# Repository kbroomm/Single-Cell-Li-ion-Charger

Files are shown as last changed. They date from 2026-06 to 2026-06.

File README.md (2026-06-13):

# Li Charger

KiCad PCB design for a single-cell lithium-ion battery charger, with a 5V USB-C input and 10-LED charge level indicator.

## Features

- **BQ24092** linear charger IC (Texas Instruments)
- **LM3914** dot/bar display driver for charge indication
- USB-C power input
- JST battery connector

## Project structure

```
├── hardware/              KiCad schematic, PCB, and custom libraries
│   ├── Li Charger.kicad_pro
│   ├── Li Charger.kicad_sch
│   ├── Li Charger.kicad_pcb
│   └── libs/              Custom symbol and footprint imports
├── manufacturing/
│   └── gerbers/           Fabrication outputs (Gerber + drill files)
├── datasheets/        	   Component reference PDFs
├── 3D models/             Component models not included in standard libs
```
## Manufacturing

Gerber and drill files for PCB fabrication are in `manufacturing/gerbers/`.

## Datasheets

| Part | Document |
|---|---|
| BQ24092  | [docs/datasheets/bq24092.pdf](docs/datasheets/bq24092.pdf) |
| LM3914 | [docs/datasheets/lm3914.pdf](docs/datasheets/lm3914.pdf) |

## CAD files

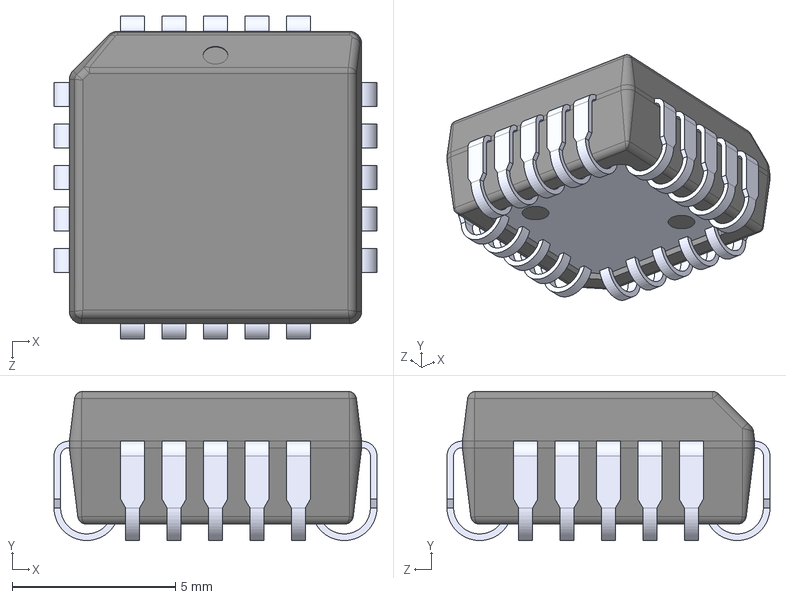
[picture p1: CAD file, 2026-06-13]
3D models/LM3914V_NOPB.STEP
9.91 x 4.57 x 9.91 mm

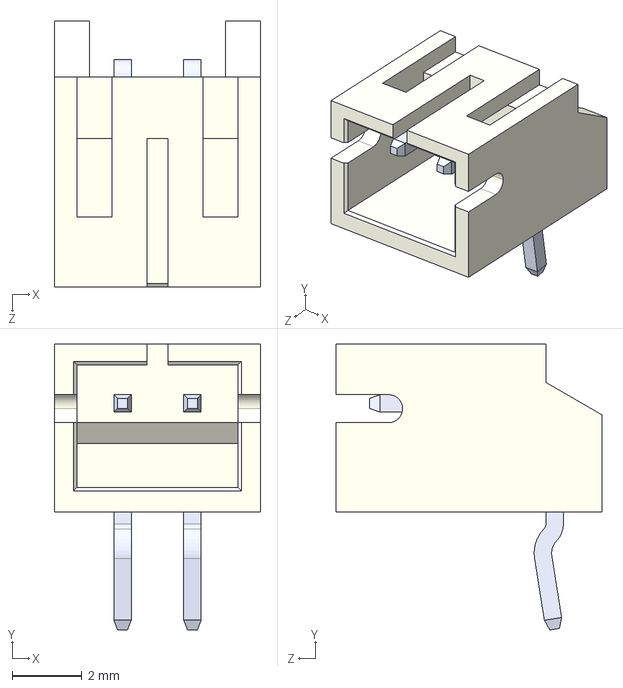
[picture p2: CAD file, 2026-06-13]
3D models/S2B-PH-K-S(LF)(SN).STEP
5.90 x 8.18 x 7.60 mm

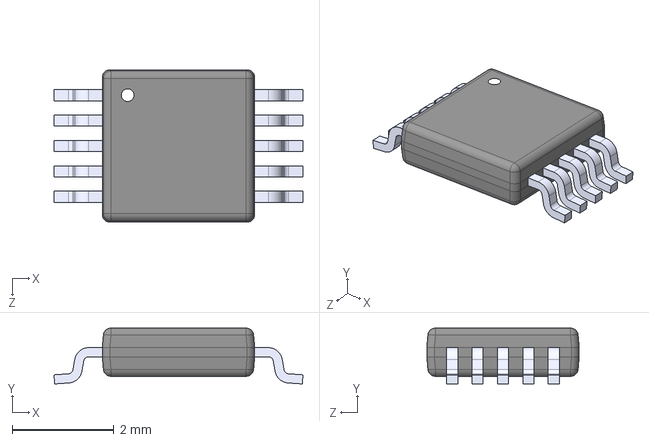
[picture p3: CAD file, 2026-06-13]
3D models/BQ24092DGQR.STEP
4.90 x 1.10 x 3.00 mm

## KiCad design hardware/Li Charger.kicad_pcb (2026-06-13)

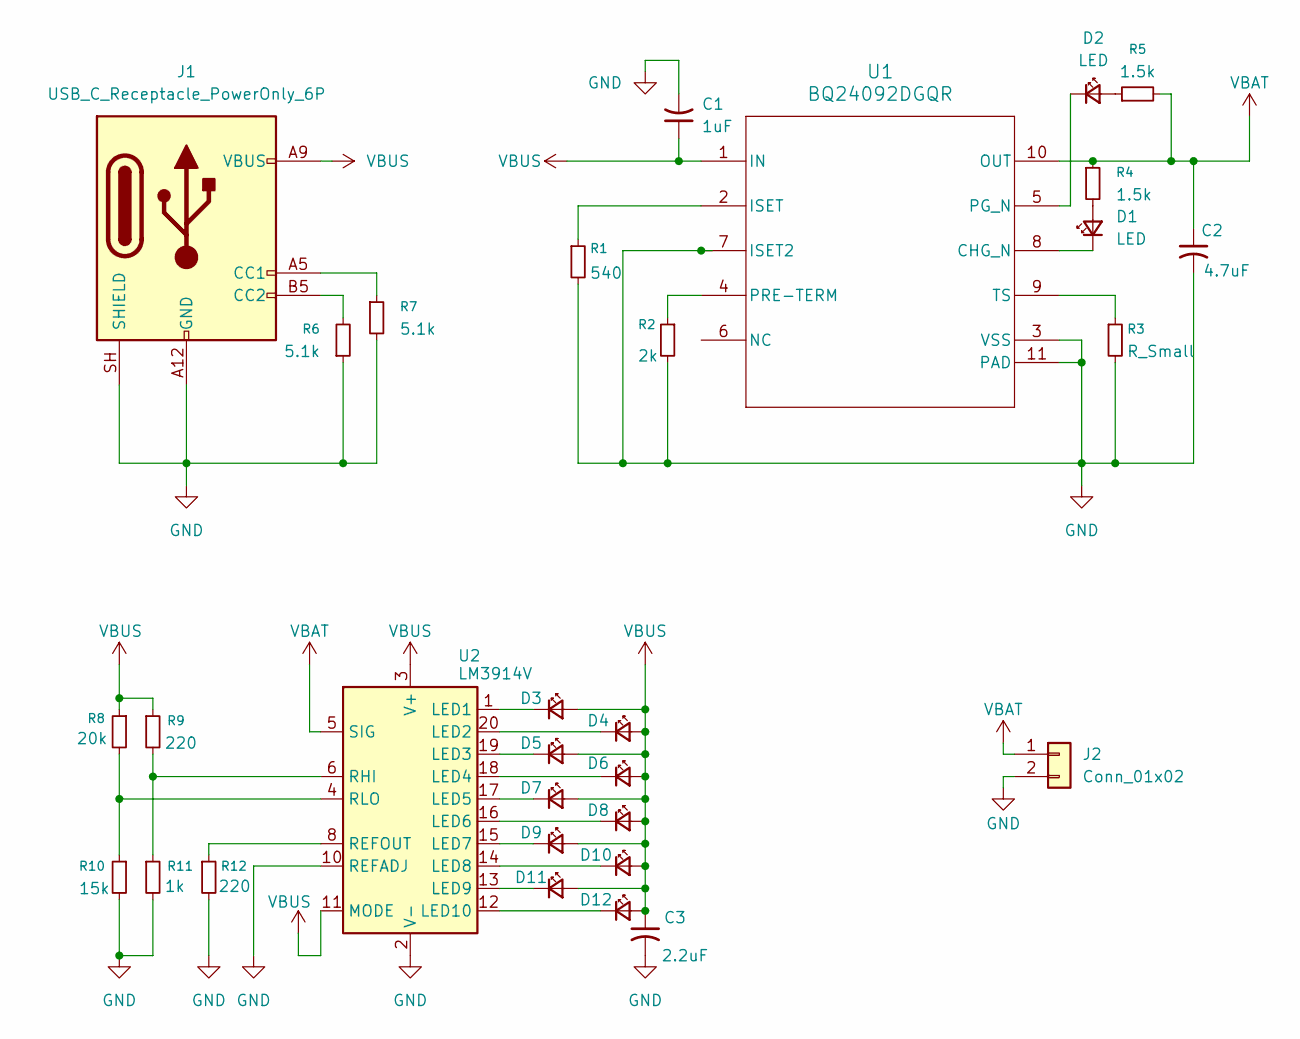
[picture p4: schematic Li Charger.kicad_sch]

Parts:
C1: 1uF; C_0805_2012Metric
C2: 4.7uF; C_0805_2012Metric
C3: 2.2uF; C_0805_2012Metric
D1, D2: LED; LED_0805_2012Metric
D3, D4, D5, D6, D7, D8, D9, D10, D11, D12: LED_Small; LED_0805_2012Metric
J1: USB_C_Receptacle_PowerOnly_6P; USB_C_Receptacle_HRO_TYPE-C-31-M-12
J2: Conn_01x02; JST_JWPF_B02B-JWPF-SK-R_1x02_P2.00mm_Vertical
R1: 540; R_0805_2012Metric
R2: 2k; R_0805_2012Metric
R3: R_Small; R_0805_2012Metric
R4, R5: 1.5k; R_0805_2012Metric
R6, R7: 5.1k; R_0805_2012Metric
R8: 20k; R_0805_2012Metric
R9, R12: 220; R_0805_2012Metric
R10: 15k; R_0805_2012Metric
R11: 1k; R_0805_2012Metric
U1: BQ24092DGQR; HVSSOP-10-1EP_3x3mm_P0.5mm_EP1.83x1.89mm
U2: LM3914V; PLCC-20

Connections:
GND: C1.2, C2.2, C3.2, J1.A12 (GND), J1.B12 (GND), J1.SH (SHIELD), J2.2, R1.2, R2.2, R3.2, R6.1, R7.2, R10.2, R11.2, R12.2, U1.3 (VSS), U1.7 (ISET2), U1.11 (PAD), U2.2 (V-), U2.10 (REFADJ); also elsewhere on the board
unnamed: D1.2 (A), R4.2
unnamed: D1.1 (K), U1.8 (CHG_N)
unnamed: D2.2 (A), R5.1
unnamed: D2.1 (K), U1.5 (PG_N)
unnamed: D3.1 (K), U2.1 (LED1)
unnamed: D4.1 (K), U2.20 (LED2)
unnamed: D5.1 (K), U2.19 (LED3)
unnamed: D6.1 (K), U2.18 (LED4)
unnamed: D7.1 (K), U2.17 (LED5)
unnamed: D8.1 (K), U2.16 (LED6)
unnamed: D9.1 (K), U2.15 (LED7)
unnamed: D10.1 (K), U2.14 (LED8)
unnamed: D11.1 (K), U2.13 (LED9)
unnamed: D12.1 (K), U2.12 (LED10)
unnamed: J1.A5 (CC1), R7.1
unnamed: J1.B5 (CC2), R6.2
unnamed: R1.1, U1.2 (ISET)
unnamed: R2.1, U1.4 (PRE-TERM)
unnamed: R3.1, U1.9 (TS)
unnamed: R12.1, U2.8 (REFOUT)
unnamed: R9.2, R11.1, U2.6 (RHI)
unnamed: R8.2, R10.1, U2.4 (RLO)
VBAT: C2.1, J2.1, R4.1, R5.2, U1.10 (OUT), U2.5 (SIG); also elsewhere on the board
VBUS: C1.1, C3.1, D3.2 (A), D4.2 (A), D5.2 (A), D6.2 (A), D7.2 (A), D8.2 (A), D9.2 (A), D10.2 (A), D11.2 (A), D12.2 (A), J1.A9 (VBUS), J1.B9 (VBUS), R8.1, R9.1, U1.1 (IN), U2.3 (V+), U2.11 (MODE); also elsewhere on the board

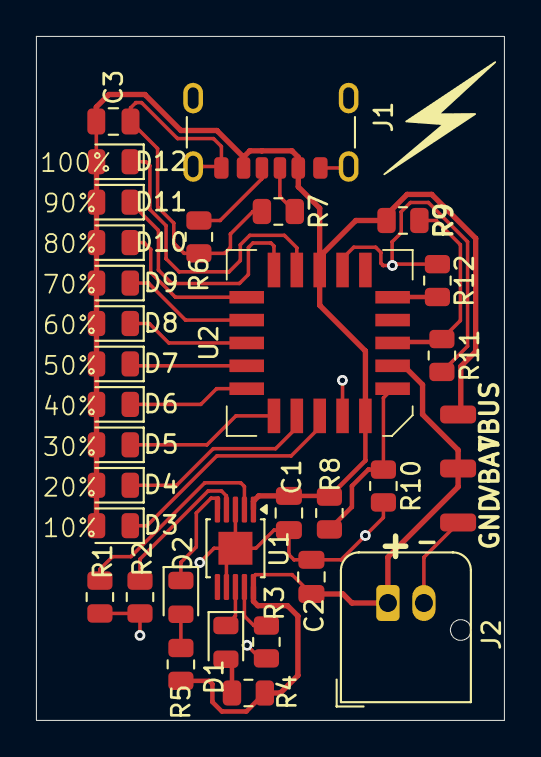
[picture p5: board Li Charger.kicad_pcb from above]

Board: 2 copper layers, 26.0 x 38.0 mm, 34 parts (0 on the bottom side), 25 nets.

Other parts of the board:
GND: SolderWirePad_1x01_SMD_1x2mm
VBAT: SolderWirePad_1x01_SMD_1x2mm
VBUS: SolderWirePad_1x01_SMD_1x2mm

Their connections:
GND: GND.1; also elsewhere on the board
VBAT: VBAT.1; also elsewhere on the board
VBUS: VBUS.1; also elsewhere on the board

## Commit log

2026-06-13 Make Repo Public
    [BQ24092DGQR.STEP, LM3914V_NOPB.STEP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]
2026-06-13 Schematic Value Update
    [Li Charger.kicad_pcb, Li Charger.kicad_sch]
